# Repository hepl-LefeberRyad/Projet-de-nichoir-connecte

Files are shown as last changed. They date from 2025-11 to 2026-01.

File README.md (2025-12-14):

# Projet-de-nichoir-connecte
## Introduction
Dans ce répertoire, nous décrivons le projet final du premier quadrimestre pour le cours Smart Cities IoT. Le projet consiste en un nichoir intelligent capable de prendre des photos grâce à un ESP32 équipé d’une caméra intégrée. La caméra est déclenchée par un capteur de mouvement et est accompagnée d’une LED permettant d’éclairer l’intérieur du nichoir.

Les photos sont ensuite envoyées à un broker via le protocole MQTT et enregistrées dans une base de données. Elles sont également accessibles sur un site web.

Le projet intègre également une batterie, et une gestion énergétique a été mise en place afin que le nichoir puisse fonctionner pendant au moins six mois. Le niveau de batterie et la tension sont envoyés au broker une fois par jour.



## Matériel utilisés
### Timer cam
Le microcontrôleur principal de ce projet est une Timer Cam, qui contient un ESP32, une caméra ainsi qu’un port pour une batterie. Ce microcontrôleur est idéal pour ce type de projet de nichoir, puisque toutes les fonctionnalités nécessaires sont déjà intégrées sur une seule carte.
https://www.mouser.be/ProductDetail/170-U082

<p align="center">
  
</p>

### Raspberry pi
Le Raspberry Pi, qui agit comme broker et qui contient également la base de données dans laquelle les images seront enregistrées, est un Raspberry Pi 5. Il sert également à créer une page web sur laquelle on pourra consulter les images enregistrées, ainsi que l’heure et la date de prise de chaque photo, et le niveau de tension et de charge de la batterie. 
<p align="center">
  
</p>

### Capteur PIR
Le capteur de mouvement utilisé dans ce projet est un capteur PIR à 6 broches. Il s’agit d’un capteur intelligent qui intègre un circuit numérique et un élément sensible dans un boîtier hermétiquement fermé. Il peut s’interfacer directement avec jusqu’à deux capteurs PIR conventionnels via une entrée différentielle à haute impédance. Le signal PIR est converti en valeur numérique directement sur la puce. Une sortie REL indique lorsque le signal PIR dépasse le seuil sélectionné. L’entrée OEN peut contrôler la sortie REL ou passer par le capteur de lumière. Les paramètres de sensibilité et de durée de détection sont réglés en connectant les entrées correspondantes à des tensions continues (DC). Tout le traitement du signal est effectué numériquement. 
https://www.mouser.be/ProductDetail/485-5578
<p align="center">
  
</p>

### LED
Puisqu’il n’y a pas de lumière à l’intérieur du nichoir, nous utilisons une LED qui s’active uniquement lorsque la caméra prend une photo.
https://www.mouser.be/ProductDetail/442-BIRHO033ATB

### Régulateur de tension 3,3V
Puisque la tension de la batterie est supérieure à 3,3 V, il est nécessaire d’ajouter un régulateur de tension, car la tension idéale pour le fonctionnement du capteur de mouvement est de 3,3 V.
https://www.mouser.be/ProductDetail/584-ADP150AUJZ-3.3R7

### Mosfet
Puisque le courant consommé par la LED est supérieur à ce que la sortie GPIO de l’ESP32 peut fournir, nous avons dû implémenter un MOSFET. Ce MOSFET agit comme un interrupteur, permettant à la LED de s’allumer uniquement lorsqu’une impulsion est appliquée à sa gate. Un GPIO de l’ESP32 est connecté à cette gate.
https://www.mouser.be/ProductDetail/771-BSS138PS115

### Résistance et condensateurs
Nous avons également dû utiliser deux condensateurs, qui agissent comme des condensateurs de découplage entre l’entrée et la sortie du régulateur de tension. Deux résistances sont utilisées pour définir la sensibilité du capteur PIR, une résistance est placée en série avec la LED pour la protéger, et une autre résistance est utilisée sur la gate du MOSFET.

### Batterie 3,7 2000mAh
La batterie utilisée dans ce projet est une batterie de 3,7 V avec une capacité de 2000 mAh.
https://hobbyking.com/fr_fr/turnigy-2000mah-1s-1c-lipoly-w-2-pin-jst-ph-connector.html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

<p align="center">
  
</p>

## Logiciel utilisé
Pour programmer l’ESP32, nous avons utilisé Arduino IDE (version 2.3.5), qui simplifie le développement grâce à l’implémentation de nombreuses bibliothèques. Pour le Raspberry Pi, nous avons utilisé le langage Python (version 3.12) pour la gestion du MQTT. Nous avons également utilisé MariaDB et MySQL pour la création des bases de données et le traitement des données. Enfin, pour la création du site web, nous avons utilisé le langage HTML.

## Hardware
Pour assurer le bon fonctionnement du projet, il est indispensable de concevoir un PCB et un boîtier afin de protéger à la fois le PCB, les composants électroniques et la batterie. Nous avons créé le boîtier en le modélisant en 3D sur Fusion 360, puis nous l’avons imprimé. Pour la conception du PCB, nous avons utilisé Altium Designer version 25.8.1. 

<p align="center">
  <br><br>
  
</p>

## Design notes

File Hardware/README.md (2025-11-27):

# Hardware
## Introduction
Dans cette partie du répertoire, nous décrivons notre progrès concernant la partie matérielle du projet, comme le PCB ou le boîtier 3D.

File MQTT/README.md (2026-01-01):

# MQTT
## Introduction 
Dans cette partie du répertoire, nous documentons notre progrès dans l’implémentation du protocole MQTT pour notre projet. Un dossier contient notre progrés avec le code en Arduino l'autre avec notre progrés en RP.
# ESP32 Communication par MQTT

## Introduction
Ce dossier contient les codes liés à la communication MQTT du module ESP32 5TimerCam. Les codes permettent d'envoyer au broker MQTT des topics contenant des données textuelles ainsi que des images.  
Les codes sont dévelloppés sur l'environnement Arduino IDE et incluent la gestion de la connexion internet du côté subscriber. 
L'échange de données s'effectue sur le réseau local, via l'adresse IP du broker MQTT.

---
## Patch hepl-SousaJoao-patch-4#  

**Objectif** 
Ce code met en place un système de double réveil pour la TimerCAM :
- Réveil immédiat via le capteur PIR pour signaler un mouvement
- Réveil périodique via le timer RTC toutes les 60 secondes
Le tout en maintenant une consommation minimale grâce au deep sleep et à un timer permanent synchronisé.

1. Configuration matérielle
- LED externe sur le GPIO4
- Capteur PIR sur le GPIO13
- TimerCAM initialisée au démarrage
- RTC interne utilisé pour mesurer le temps et programmer les réveils

2. Gestion des causes de réveil
Au démarrage, le code identifie la source du réveil :

a) Réveil par PIR (EXT0)
- Le PIR est passé à HIGH
- La LED externe s’allume pendant 10 secondes
- Puis elle s’éteint avant le retour en deep sleep
  Ce comportement simule une action simple lors d’un mouvement détecté.

b) Réveil par Timer RTC
- Le timer interne a atteint l’échéance programmée
- Le code affiche simplement : "Reveil par timer permanent"
  Ce réveil sert uniquement à maintenir la synchronisation du timer.

c) Premier démarrage / reset
- Initialisation du timer permanent
- next_wakeup = now + PERIOD_US
  Le premier réveil périodique est programmé exactement 60 secondes plus tard.

3. Timer RTC permanent 
Le code utilise une variable RTC persistante :
RTC_DATA_ATTR uint64_t next_wakeup;

Elle survit au deep sleep et permet de :
- Garder une échéance fixe dans le temps
- Éviter toute dérive, même après plusieurs réveils PIR
- Recalculer la durée restante avant le prochain réveil
Logique :
- On lit l’heure RTC 
- On calcule le temps restant
- Ce temps restant est utilisé pour programmer le prochain réveil timer

Le réveil périodique reste parfaitement aligné toutes les 60 secondes.

4. Réactivation des sources de réveil
Avant chaque deep sleep :
- Le capteur PIR est activé :
esp_sleep_enable_ext0_wakeup(SENSOR_PIN, 1);
- Timer RTC est activé avec la durée restante :
esp_sleep_enable_timer_wakeup;
Ainsi, l’ESP32 peut être réveillé :
- Instantanément par un mouvement
- Régulièrement par le timer interne
- Sans conflit entre les deux mécanismes

5. Deep sleep
Enfin, le module entre en veille profonde:

esp_deep_sleep_start();

Le loop() n’est jamais exécuté : tout se passe dans setup() à chaque réveil.

---

## Patch hepl-SousaJoao-patch-5# 
**Objectif** 

Ce firmware combine deux mécanismes de réveil pour la TimerCAM :
     - Réveil PIR pour allumer une LED lors d’un mouvement
     - Réveil périodique RTC toutes les 60 secondes
Le tout avec une fenêtre PIR de 10 minutes limitant le nombre d’activations à 2, et un timer permanent synchronisé pour éviter toute dérive temporelle.

1. Configuration matérielle
     - LED externe sur le pin GPIO4
     - Capteur PIR sur le pin GPIO13 
     - TimerCAM initialisée au démarrage
     - RTC interne utilisé pour mesurer le temps et gérer les fenêtres

2. Gestion du réveil PIR
Lors d’un réveil par le capteur PIR :
     - Vérification de la fenêtre PIR de 10 minutes :
     - Si première activation ou fenêtre expirée: remise à zéro, déboute une nouvelle fenêtre
     - Limitation à 2 déclenchements de la LED.
     - La LED s'allumée pendant 10 secondes
     - Sinon la LED est ignorée quand la limite est atteinte

Ce mécanisme évite les déclenchements répétés et stabilise la consommation.

3. Réveil par Timer RTC
Si le réveil provient du timer interne :
     - Le code affiche simplement :"Reveil par timer permanent"
Ce réveil n’exécute aucune action fonctionnelle :
il sert uniquement à maintenir la synchronisation du timer permanent.

4. Premier démarrage
 Lors d’un reset ou du tout premier boot :
   - Initialisation du timer permanent :
     - Initialisation de la fenêtre PIR
     - Remise à zéro du compteur PIR

5. Timer RTC permanent 
 Le code utilise une variable RTC persistante :

 Elle permet de :
  - Garder une échéance fixe toutes les 60 secondes
  - Recalculer le temps restant avant le prochain réveil
  - Éviter toute dérive, même après plusieurs réveils PIR
 
 Logique :
  -  Si l’heure actuelle dépasse l’échéance alors on programme la suivante
  -  Sinon, on calcule le temps restant
  -  Ce temps est utilisé pour programmer le réveil RTC

6. Activation des sources de réveil
 Avant chaque deep sleep :
  - Le capteur PIR activé
  - Timer RTC est activé avec la durée restante

Ainsi, l’ESP32 peut être réveillé :

  - Instantanément par le PIR
  - Régulièrement par le timer RTC
  - Sans conflit entre les deux mécanismes

---

## Patch hepl-SousaJoao-patch-6#  
**Objectif** 
Gestion PIR limitée, envoi batterie MQTT et timer RTC synchronisé.
Ce code met en ouvre un fonctionnement basse consommation combinant trois mécanismes indépendants:
- Déclenchement par le capteur PIR limité à deux activations dans une fenêtre de dix minutes.
- Envoi périodique de l’état de la batterie via MQTT lors d’un réveil par timer RTC.
- Deep sleep systématique avec double source de réveil : capteur PIR (EXT0) et timer RTC.
L’ensemble garantit une consommation minimale tout en assurant un comportement prévisible et synchronisé.

1. Configuration matérielle et réseau
- LED sur GPIO4
- PIR sur GPIO13 (réveil EXT0)
- TimerCAM initialisée au démarrage
- Wi‑Fi activé uniquement lors des transmissions MQTT
- MQTT configuré avec un broker local et un topic batterie

2. Gestion du réveil PIR
Lors d’un réveil PIR :
- Vérification de la fenêtre de dix minutes ; réinitialisation si expirée
- Si pir_count < 2, l’activation est acceptée : incrément du compteur et LED allumée dix secondes
- Si la limite est atteinte, aucune action n’est effectuée
Ce mécanisme limite les déclenchements et réduit la consommation.

3. Réveil par timer RTC et envoi de la batterie
Lors d’un réveil TIMER :
- Lecture du niveau et de la tension de batterie
- Construction d’un message unique
- Activation du Wi‑Fi, connexion MQTT, publication sur timercam/battery
- Désactivation immédiate du Wi‑Fi
Le Wi‑Fi n’est utilisé que pour l’envoi, ce qui optimise l’énergie.

4. Premier démarrage
En cas de reset :
- Initialisation du timer permanent, prochaine échéance dans une minute
- Initialisation de la fenêtre PIR
- Remise à zéro du compteur PIR

5. Timer RTC permanent et synchronisation
Le timer utilise next_wakeup stocké en RTC pour maintenir une périodicité stable :
- Si l’échéance est dépassée, une nouvelle est programmée
- Sinon, le temps restant est calculé
- Le timer RTC est configuré avec cette durée
Ce procédé évite toute dérive, même après plusieurs réveils PIR.

6. Activation des sources de réveil
Avant chaque deep sleep :
- Activation du réveil PIR (EXT0)
- Activation du réveil TIMER avec la durée restante
L’ESP32 peut ainsi être réveillé soit par un mouvement, soit par le timer périodique.

---    

## Patch hepl-SousaJoao-patch-7#
**Objectif :** Envoi d'une photo MQTT après détection de mouvement prolongée.  
Le but est de détecter un mouvement via un capteur PIR, attendre que ce mouvement dure au moins 10 secondes, capturer une photo avec la TimerCAM et l’envoyer vers un broker MQTT en morceaux (chunks) encodés en Base64.

- Configuration matérielle
  - Capteur PIR connecté sur la pin 13
  - Lecture en numérique : HIGH = mouvement détecté
  - TimerCAM initialisée en mode caméra JPEG
  - Résolution configurée en XGA 
  - Orientation verticale inversée via set_vflip(1)

- Connexion WiFi
  - Connexion au réseau WiFi défini dans les macros WIFI_SSID et WIFI_PASSWORD
  - Timeout de connexion fixé à 10 secondes 
  - Reconnexion automatique activée
  - Affichage de l’adresse IP en cas de réussite

- Communication MQTT
  - Utilisation de la librairie PubSubClient
  - Connexion au broker MQTT défini par :
    - MQTT_HOST
    - MQTT_PORT
    - MQTT_TOPIC
  - Reconnexion automatique si la communication MQTT est perdue
  - Envoi des messages via mqttClient.publish

- Détection de mouvement
  - La logique du PIR fonctionne en trois phases :
    
    1 - Détection du front montant
       - Passage LOW à HIGH
         
       - Début de la temporisation : motionStart = millis()
         
       - Le flag photoTaken = false réactive la prise de photo

    2 - Maintien du mouvement
       - On attend 10 secondes de mouvement continu
         
       - Condition : millis() - motionStart >= 10000
         
       - Une fois la durée atteinte une photo est capturée

    3 - Fin du mouvement
       - Passage HIGH à LOW
         
       - Reset de l’état du capteur

- Capture et envoi de la photo
  - Prise de vue via TimerCAM en JPEG
  - Découpage de l’image en blocs de 4 KB
  - Encodage en Base64 pour compatibilité MQTT
  - Transmission séquentielle de tous les chunks
  - Libération de la mémoire caméra
    
---

## Patch hepl-SousaJoao-patch-8#
**Objectif :** Envoi d'une photo MQTT après détection de mouvement prolongée avec une mise en veille.  
Détecter un mouvement continu durant 10 secondes, activer le WiFi, envoyer une photo via MQTT, puis repasser l’ESP32 TimerCAM en mode veille profonde avec réveil par le capteur PIR.

- Configuration matérielle
  - Capteur PIR sur GPIO13
  - TimerCAM initialisée en mode JPEG
  - Résolution XGA
  - Orientation verticale ajustée et qualité optimisée
  - Port série actif pour le debug

- Détection de mouvement 
  - Le PIR pilote l’ensemble du fonctionnement à travers trois phases :
    - Début du mouvement
      - Passage de LOW à HIGH.
      - Enregistrement du temps de début.
      - La prise de photo n’est pas encore autorisée.

    - Mouvement continu pendant 10 secondes
      - Si le PIR reste HIGH pendant 10 secondes il y a un déclenchement de la capture.
      - Le système sait que le mouvement est réel et persistant.

    - Fin du mouvement
      - Retour à LOW ainsi le retour à l’état initial.

- Connexion WiFi

  - Activation du WiFi uniquement lorsque la photo doit être envoyée.
  - Connexion au point d’accès défini dans le code.
  - Affichage de l’adresse IP pour vérifier la liaison.
  - Extinction complète du WiFi après envoi pour économiser l’énergie.

- Communication MQTT

  - Configuration du broker: L'adresse IP, port et topic.
  - Connexion MQTT juste avant l’envoi de la photo.
  - Reconnexion si nécessaire.
  - Transmission d’un message texte “Photo taken” après l’image.

- Capture et envoi de la photo

  - Capture JPEG via TimerCAM.
  - Découpage en blocs de 4 KB.
  - Encodage Base64 pour compatibilité MQTT.
  - Envoi séquentiel de chaque chunk identifié par:
    - ID unique: timestamp.
    - Numéro du chunk.
    - Nombre total de chunks.
  - Libération du buffer caméra après transmission.

- Mise en veille après envoi
  
  - Extinction complète du WiFi: disconnect et WIFI_OFF.
  - Attente du retour du PIR à LOW jusqu’à 10 secondes.
  - Configuration du réveil via ext0_wakeup sur le PIR.
  - Passage en deep sleep pendant 20 secondes via TimerCAM si aucune photo est prise.
    - Cela permet :
      - Réduction très forte de la consommation énergétique.
      - Réveil automatique dès qu’un nouveau mouvement est détecté.
---

## Patch hepl-SousaJoaopatch-9#
**Objectif :** Envoi d'une photo MQTT avec flash après détection de mouvement prolongée avec une mise en veille .  
Détecter un mouvement continu durant 10 secondes, signaler la prise de photo via une LED externe, envoyer l’image en plusieurs blocs sur MQTT, puis repasser l’ESP32 TimerCAM en mode veille profonde avec réveil via le PIR.

- Configuration matérielle
  - Capteur PIR connecté sur GPIO13
  - LED externe sur GPIO4
  - TimerCAM initialisée pour capturer en JPEG 
  - Port série configuré pour le suivi en temps réel
  - Paramètres MQTT définis: broker local, topic

- Détection du mouvement
  - Le programme suit l’évolution du signal du PIR :
  - Début du mouvement: LOW à HIGH
  - Enregistrement du temps de début
  - Indication dans le terminal
  - L’appareil se prépare mais ne prend pas encore de photo

- Mouvement continu pendant 10 secondes
  - Vérification via millis()
  - Ce seuil valide que la présence détectée est réelle et prolongée

- Fin du mouvement 
  - Réinitialisation du système
  - Retour en état d’attente

- Indication lumineuse
  - La LED s’allume juste avant la capture photo
  - Elle reste active pendant la transmission MQTT
  - Elle s’éteint 2 secondes après la photo, comme flash

- Connexion WiFi et communication MQTT
  - Activation du WiFi uniquement lors de la prise de photo
  - Connexion au réseau local configuré
  - Connexion MQTT au broker via un client PubSub
  - Envoi d’un message “Photo taken” après le transfert de l’image
  - Désactivation totale du WiFi après transmission

- Capture et envoi de la photo
  - Capture JPEG via TimerCAM
  - Découpage du fichier en blocs de 4 KB
  - Encodage Base64 de chaque bloc
  - Envoi sur le topic MQTT sous forme de paquets :

    - ID de l’image
      - Numéro du bloc
      - Nombre total de blocs
      - Données base64

  - Libération du buffer caméra après transmission

- Mise en veille et gestion du réveil
  - Attente que le PIR repasse à LOW avant d’autoriser la veille
  - Configuration du réveil matériel via ext0_wakeup sur le capteur PIR
  - Passage en mode deep sleep pendant 20 secondes si aucune photo est prise
  - L’ESP32 se réveillera automatiquement lorsqu’un nouveau mouvement est détecté

    - Ce fonctionnement permet :
      - Une détection fiable
      - Une transmission réseau efficace
      - Une consommation d’énergie minimale grâce à la veille profonde

---

## Patch hepl-SousaJoaopatch-10# 
**Objectif :** Détecter un mouvement continu pendant 10 secondes, capturer une photo, l’envoyer en blocs via MQTT, puis remettre la TimerCAM en deep sleep avec double réveil :
   - Par capteur PIR (EXT0) pour prendre les photos
   - Par timer RTC pour l’envoi périodique du niveau de batterie.
 Ce patch combine détection fiable, transmission optimisée, et gestion d’énergie avancée.

1. Configuration matérielle
   - Capteur PIR sur le GPIO13
   - LED externe sur GPIO4
   - TimerCAM initialisée pour capturer en JPEG 
   - WiFi activé uniquement lors des transmissions
   - MQTT : broker local, topics pics et timercam/battery

2. Détection du mouvement avec la PIR:

   - Vérification que le PIR est HIGH 
   - Démarrage d’une fenêtre de 10 secondes via millis()
   - Si le signal reste stable : photo autorisée
   - Sinon : retour immédiat en veille
  Une limite de 2 photos par fenêtre de 10 minutes est imposée via :
   - window_start (timestamp RTC)
   - pir_count => compteur de photos max. 2 photos par fenêtre de temps

3. Capture et envoi de la photo

 Si le mouvement est continu pendant 10 secondes:
   - Initialisation caméra
   - Capture JPEG
   - Découpage en blocs de 4095 bytes
   - Encodage Base64
   - Envoi MQTT sous forme de données_base64
   - Message final : "Photo taken"
   - Libération du buffer caméra
   - Désactivation du WiFi

4. Envoi périodique de la batterie (réveil par le TIMER)
 Toutes les 1 minute, un réveil RTC est déclenché :
   - Lecture tension + pourcentage batterie
   - Connexion WiFi + MQTT
   - Publication sur timercam/battery
   - Retour en deep sleep
 Ce réveil n’interfère pas avec la logique PIR.

5. Gestion des timers RTC 
 a) Réveil toutes les 60 secondes pour envoyer l’état batterie.
    #define PERIOD_US (60ULL * 1000000ULL)

 b) WINDOW_US – Fenêtre PIR de 10 minutes
    Limite de 2 photos par fenêtre de 10 minutes.
    Si la fenêtre expire, pir_count est remis à zéro. 
    #define WINDOW_US (10ULL * 60ULL * 1000000ULL)

 c) next_wakeup – Synchronisation continue
    Stocké en RTC_DATA_ATTR, donc conservé en deep sleep.
    Logique :
   - On calcule le temps restant avant le prochain réveil périodique
   - On programme le timer RTC avec ce temps
   - On met à jour next_wakeup = now + remaining

 Le réveil batterie reste parfaitement synchronisé, même si plusieurs réveils PIR interviennent entre-temps.

  6. Mise en veille et réveils
   
  Avant de dormir :
   - Activation du réveil PIR :
     esp_sleep_enable_ext0_wakeup(SENSOR_PIN, 1)
   - Activation du réveil timer :
     esp_sleep_enable_timer_wakeup(remaining)
   - Passage en deep sleep
 Ce fonctionnement assure :
   - Réactivité avec un réveil instantané sur mouvement
   - Régularité avec le niveau de batterie envoyée toutes les 60 s
   - Économie d’énergie maximale

---

## Patch hepl-SousaJoaopatch-11#
**Objectif** L’objectif est de faire fonctionner la TimerCAM en ultra basse consommation en combinant trois fonctions totalement indépendantes : la prise de photo uniquement lorsqu’un mouvement est validé par le capteur PIR, l’envoi périodique de l’état de la batterie via MQTT, et un mode deep sleep optimisé utilisant deux sources de réveil — le PIR pour les photos et le timer RTC pour les transmissions programmées.

1. Matériel et configuration
   
- Capteur PIR sur le pin GPIO13 (EXT0)
- LED externe sur le pin GPIO4
- Initialisation de la TimerCAM
- Initialisation du Wi-Fi
- Initialisation de la communication par MQTT 

2. Réveil par détection d'un mouvement par le capteur PIR  
 Au réveil par le PIR :

 - Vérification du contexte s'il n'y a pas de blocage ou si la fenêtre PIR active
 - Validation du mouvement :
  - Observation du PIR pendant 10 s
  - Le signal doit rester majoritairement HIGH
  - Sinon: retour en deep sleep
 - Limitation : 2 photos maximum par fenêtre de 12h  
  - window_start = début de fenêtre
  - pir_count = nombre de photos prises

3. Capture & envoi photo
   
Si le mouvement est validé :
- Initialisation caméra
  - Capture d'une image
  - Découpage en blocs de 4095 octets
  - Encodage Base64
  - Envoi MQTT des chunks de la photo
  - Message final : "Photo taken"
  - Libération mémoire + coupure Wi-Fi
- Activation d’un blocage PIR de 5 minutes

4. Blocage PIR
   
Après chaque photo :
- Le PIR est ignoré pendant 5 minutes
- Le timer RTC gère automatiquement la fin du blocage
- Objectif : éviter les rafales et réduire la consommation

5. Batterie réveil par TIMER
   
Un réveil RTC indépendant envoie la batterie toutes les 24 h :
- Lecture tension + le pourcentage de la batterie
- Publication MQTT sur battery
- Coupure Wi-Fi
- Retour en deep sleep
Ce réveil fonctionne même si plusieurs réveils PIR ont eu lieu entre-temps.

6. Gestion des timers RTC
   
- Timer batterie :
- Stocké en RTC
- Toujours aligné sur un multiple exact de 24 h
- Fenêtre PIR :
- Durée : 12 h
- À expiration alors pir_count = 0
- Avant chaque deep sleep :
- Calcul du prochain événement :
- Envoi batterie
- Fin blocage capteur PIR
- Fin fenêtre capteur PIR
- Le plus proche détermine la durée du sommeil

7. Mise en veille
   
Avant de dormir :
- Timer RTC toujours actif
- PIR activé uniquement si : Pas de blocage ou si la fenêtre PIR n'est pas saturée.
- Fenêtre PIR non saturée

Réveil après dormir si :
- Réveil instantané sur mouvement valide
- Batterie envoye les données régulièrement
- Ce qui permet une consommation minimale

---

## Patch hepl-SousaJoaopatch-12#

**Objectif** Faire fonctionner la TimerCAM en ultra basse consommation : capture photo uniquement sur mouvement validé par le PIR, envoi périodique de la batterie via MQTT, et deep sleep optimisé avec GPIO33 pour alimentation de la caméra, capteur PIR et les timers RTC.

1. Matériel et configuration

- Capteur PIR sur le pin GPIO13 (EXT0)
- LED externe sur le pin GPIO4
- Initialisation du  GPIO33 poour commuter la batterie
- Initialisation de la TimerCAM
- Initialisation du Wi-Fi
- Initialisation de la communication par MQTT 
- GPIO 33 est mis sur HIGH en permanence

2. Réveil par détection d'un mouvement par le capteur PIR  
 Au réveil par le PIR :

 - Vérification du contexte s'il n'y a pas de blocage ou si la fenêtre PIR active
 - Validation du mouvement :
  - Observation du PIR pendant 10 s
  - Le signal doit rester majoritairement HIGH
  - Sinon: retour en deep sleep
 - Limitation : 2 photos maximum par fenêtre de 12h  
  - window_start = début de fenêtre
  - pir_count = nombre de photos prises

3. Capture & envoi photo
   
Si le mouvement est validé :
- Initialisation caméra
  - Capture d'une image + envois de la topic de la batterie
  - Découpage en blocs de 4095 octets
  - Encodage Base64
  - Envoi MQTT des chunks de la photo
  - Message final : "Photo taken"
  - Libération mémoire avec coupure Wi-Fi
- Activation d’un blocage PIR de 5 minutes

4. Blocage PIR
   
Après chaque photo :
- Le PIR est ignoré pendant 5 minutes
- Le timer RTC gère automatiquement la fin du blocage
- Objectif : éviter les rafales et réduire la consommation

5. Batterie réveil par TIMER
   
Un réveil RTC indépendant envoie la batterie toutes les 24 h :
- Lecture tension + le pourcentage de la batterie
- Publication MQTT sur battery
- Coupure Wi-Fi
- Retour en deep sleep
Ce réveil fonctionne même si plusieurs réveils PIR ont eu lieu entre-temps.

6. Gestion des timers RTC
   
- Timer batterie :
- Stocké en RTC
- Toujours aligné sur un multiple exact de 24 h
- Fenêtre PIR :
- Durée : 12 h
- À expiration alors pir_count = 0
- Avant chaque deep sleep :
- Calcul du prochain événement :
- Envoi batterie
- Fin blocage capteur PIR
- Fin fenêtre capteur PIR
- Le plus proche détermine la durée du sommeil

7. Mise en veille
   
Avant de dormir :
- Timer RTC toujours actif
- PIR activé uniquement si : Pas de blocage ou si la fenêtre PIR n'est pas saturée.
- Fenêtre PIR non saturée

Réveil après dormir si :
- Réveil instantané sur mouvement valide
- Batterie envoye les données régulièrement
- Ce qui permet une consommation minimale

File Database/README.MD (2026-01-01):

# Database

## Introduction
Ce dossier contient le code et les scripts relatifs à la gestion des données du projet SmartCitiesIoT – Nichoir.  
Il inclut la configuration de la base de données MariaDB, la création de tables pour stocker les messages et les images envoyés par l'ESP32 via MQTT, ainsi que les scripts Python pour insérer et récupérer ces données.

---

## Patch #1
**Objectif :** Gestion des messages envoyés par l'ESP32 via MQTT.  
- Création de la base `IMAGE` et de la table `messages`.  
- Champs principaux de la table `messages` :
  - `id` : identifiant unique auto-incrémenté.  
  - `topic` : topic MQTT associé au message.  
  - `payload` : contenu du message (texte).  
  - `timestamp` : date et heure de réception automatique.  
- Script Python fourni pour :
  - Créer la table si elle n’existe pas (`create_table()`).  
  - Recevoir des messages MQTT et les insérer dans la base (`insert_message()`).  
- Utilisation d’un client MQTT en Python (`paho-mqtt`) avec gestion de la reconnexion automatique.

---

## Patch #2
**Objectif :** Réception et stockage des images envoyées en un seul paquet.  
- Création de la table `images` pour stocker les photos.  
- Champs principaux :
  - `id` : identifiant unique auto-incrémenté.  
  - `topic` : topic MQTT associé à l'image.  
  - `payload` : données binaires de l'image (BLOB).  
  - `timestamp` : date et heure de réception.  
- Script Python fourni pour :
  - Décoder les images envoyées en Base64.  
  - Sauvegarder les images :
    - Dans le dossier local `/home/joao1/received_images`.  
    - Dans la base de données MariaDB (`images`).  
- Gestion des erreurs de connexion et de décodage des images.

---

## Patch #3
**Objectif :** Gestion des images envoyées en plusieurs morceaux (chunking).  
- Réception des images chunkées pour permettre l’envoi de fichiers plus volumineux.  
- Structure temporaire : dictionnaire `image_chunks` pour stocker les morceaux d’images en mémoire.  
- Fonctionnalités principales :
  - Assemblage des chunks dans le bon ordre pour reconstituer l'image complète.  
  - Décodage Base64 de l’image reconstituée.  
  - Sauvegarde automatique :
    - Dans le dossier local `/home/joao1/received_images`.  
    - Dans la base de données MariaDB (`images`) avec `imageID`.  
  - Gestion de la mémoire pour supprimer les chunks après assemblage.  
  - Logs détaillés pour suivre la réception et le traitement des images.

--- 
## Patch #10
**Objectif :** Gestion des images envoyées en plusieurs morceaux (chunking) et ajout de la réception des informations de batterie via MQTT.

### Nouveautés
- **Gestion du topic batterie (`battery`)**
  - Prise en charge des messages MQTT envoyés par l'ESP32 contenant l’état de la batterie.
  - Format attendu : `"LEVEL,VOLTAGE"` (exemple : `"85,3700"`).
  - Extraction automatique de :
    - `battery_level` : niveau de batterie en pourcentage.
    - `battery_voltage` : tension en millivolts.
  - Affichage des informations dans les logs avec horodatage.
  - Gestion des erreurs pour les messages mal formés ou inattendus.

- **Adaptation des callbacks MQTT**
  - Les callbacks gèrent désormais simultanément :
    - Le topic images (`pics`) avec réception chunkée.
    - Le topic batterie (`battery`) sans perturber le traitement des images.

- **Suivi temps réel de l’état énergétique**
  - Permet de suivre l’état de la batterie de l’ESP32 via MQTT en parallèle de la réception et de la sauvegarde des images.

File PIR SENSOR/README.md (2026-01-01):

# PIR SENSOR

## Introduction
Ce dossier contient les codes de base relatifs à la gestion du capteur PIR 5578 BS-612 sur un ESP32 5TimerCam.  
Ce code est écrit sur l'environnement Arduino IDE et permet la configuration de base du capteur, ainsi que contrôler les moyens d'activation et désactivation du capteur.

---

## Patch hepl-SousaJoao-patch-1#
**Objectif :** Test simple du capteur BS-612 qui contrôle l'état d'une led.  

- Configuration des pins du matérielle
  - Le capteur PIR BS-612 est configuré comme une entrée sur le GPIO13.
  - La led est configuré comme sortie sur le pin GPIO4.
- Lecture de l'état du capteur
  - Il y a une surveillance continue de l'état logique du capteur PIR.
  - Lorsqu'il y a une détection d'un front montant, le capteur se met en état HIGH.
- Activation de la LED
  - La led s'allume lors de la détection
  - Grâce au compteur millis(), le programme peut vérifier si la led est allumée depuis 5000ms.
- Gestion de la temporisation
  - Comptage jusqu'à 5000ms avant que la led s'éteint.
  - Utilisation d'un flag (ledActive) pour éviter des déclenchements répétés.
- Coupure automatique de la led
  - La led s'éteint.   

## Patch hepl-SousaJoao-patch-2#
**Objectif :** Détecter un mouvement avec le capteur PIR BS-612 et allumer la led uniquement si le mouvement dure au moins 5 secondes.  

- Configuration des pins du matérielle
  - Le capteur PIR BS-612 est configuré  sur le GPIO13 et la led sur le pin GPIO4.
  - L'initialisation de la led à l'état LOW.
- Lecture de l'état du capteur
  - Il y a une surveillance continue de l'état logique du capteur PIR.
  - Lorsqu'il y a une détection d'un front montant, le capteur se met en état HIGH.
- Démarrage du chronomètre sur détection
  - Quand un mouvement est capté, pour la première fois:
    - motionDetected = true
    - motionStartTime = millis(), il y a un enregistrement du moment du début du mouvement.
- Vérification de la durée du mouvement
  - Si le mouvement continue est égale ou dépasse 5 secondes alors:
    - La led s'allume.
    - Un message est envoyé sur le terminal:
- Réinitialisation si pas de mouvement
  - motionDeected = false
  - si la led est allumée, et il n'y a plus de mouvement continue: la led s'éteint.

## Patch hepl-SousaJoao-patch-3#
**Objectif :** Réveil du microcôntroleur grâce au capteur PIR BS-612.  

- Configuration des pins du matérielle
  - Le capteur PIR BS-612 est configuré  sur le GPIO13 et la led sur le pin GPIO4.
  - L'initialisation de la led à l'état LOW.
- Réveil par bouton ou capteur
  - Autorisation du réveil depuis l’état de sommeil profond (esp_sleep_enable_ext0_wakeup)
  - Niveau bas sur le bouton ou le capteur déclenche le réveil
  - Permet de garder l’appareil en veille pour économiser de l’énergie
- Gestion du TimerCAM
  - Initialisation du module TimerCAM (TimerCAM.begin(true))
  - Commande d’allumage de la LED via PWM 
  - LED allumée pendant 10 secondes pour indiquer le réveil

- Mise en veille automatique
  - Après affichage / temporisation, l’appareil peut se mettre en veille
  - Le réveil peut être déclenché par :
  - le capteur PIR
  - le bouton physique
  - La fonction TimerCAM.Power.timerSleep(5) déclenche la mise en veille après 5 secondes

- Utilisation du compteur / temporisation
  - vTaskDelay(pdMS_TO_TICKS(10000)) = pause non bloquante pendant 10 secondes avant de lancer la veille
  - Permet d’avoir un délai avant la mise en veille tout en restant compatible avec le multitâche

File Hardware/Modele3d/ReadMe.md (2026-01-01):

## Modele3d
Dans ce dossier on retrouve les modèles 3d de notre projet. Volume 1 était un premier boîtier qu'on a developpé et volume 2 est le prototype final.

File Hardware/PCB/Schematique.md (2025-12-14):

# Schematique 
La schématique suivante montre le branchement des composants principaux du projet.



## MOSFET et LED
La tension provient du pin Nr3 du bus de la Timer Cam. Le pin Nr1 du bus correspond au GPIO 13, utilisé pour le capteur PIR, tandis que le pin Nr2 correspond au GPIO 4. Le GPIO 4 est connecté à la gate du MOSFET, et à la source, on trouve une résistance en série avec la LED.

Lorsqu’une impulsion est envoyée sur le GPIO 4, le MOSFET conduit et la LED est connectée à la masse, ce qui permet son allumage.

Pour cette application, nous avons utilisé un IC avec deux MOSFET intégrés, car le MOSFET idéal n’était plus disponible chez Mouser. Le MOSFET choisi est le BSS138PS, adapté pour être activé directement par un GPIO d’un ESP32.
La résistance R4, en série avec la LED, limite le courant à 50 mA et fait chuter la tension de 3,3 V à 1,3 V, protégeant ainsi la LED. La résistance R1, en série avec la gate du MOSFET, limite le courant de charge instantané de la gate à environ 10 mA, protégeant le GPIO de l’ESP32 tout en assurant une commutation rapide. Ces deux résistances garantissent donc la sécurité et le fonctionnement fiable du circuit.

### Caractéristiques du BSS138PS:
- Courant maximal : 320 mA (suffisant pour notre LED consommant 50 mA max)
- Tension drain-source maximale : 60 V
- Tension gate-source maximale : ±20 V
- Tension seuil gate-source (VGS(th)) : 0,9 – 1,5 V

## Régulateur de tension
Nous avons également utilisé le régulateur ADP150AUJZ-3,3R7, un régulateur à ultra faible bruit garantissant une tension de sortie stable de 3,3 V. Deux condensateurs de découplage de 1 µF sont branchés respectivement à l’entrée et à la sortie du régulateur de tension.

### Caractéristiques principales :
- Tension d’entrée : 2,2 V à 5,5 V

- Courant maximal : 150 mA (largement suffisant pour notre application)

## Résistance au Pin REL du PIR
Le pont diviseur, composé de R3 et R2, permet de régler la sensibilité du capteur. Plus la tension au point de mesure se rapproche de 0 V, plus le capteur est sensible. Dans notre application, nous avons utilisé 100 Ω et 1 kΩ. T1 représente un point de test permettant de mesurer la tension du diviseur.
# PCB
Le PCB a été commandé chez EUROCIRCUIT et présente une taille compacte de 3,3 cm de largeur sur 4,3 cm de longueur, afin de s’insérer facilement dans un petit boîtier, minimisant ainsi l’encombrement dans le nichoir. Il comporte deux couches et intègre à la fois des composants SMD et through-hole.
<p align="center">
 
</p>

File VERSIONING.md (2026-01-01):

# Versioning

Chaque changement apporté aux codes a été réalisé en utilisant une nouvelle branche.  
La branche `main` contient le code principal avec l’ensemble des fonctionnalités du projet.

Dans chaque branche créée, un fichier README décrit les changements apportés aux différents fichiers du code.  
Dans ce README, nous rassemblons l’ensemble des différents patchs appliqués à notre projet afin d’assurer un suivi clair et structuré de son évolution.

## Patchs effectuer par Ryad
---

## Patch #1
**Objectif :** Gestion des messages envoyés par l'ESP32 via MQTT.  
- Création de la base `IMAGE` et de la table `messages`.  
- Champs principaux de la table `messages` :
  - `id` : identifiant unique auto-incrémenté.  
  - `topic` : topic MQTT associé au message.  
  - `payload` : contenu du message (texte).  
  - `timestamp` : date et heure de réception automatique.  
- Script Python fourni pour :
  - Créer la table si elle n’existe pas (`create_table()`).  
  - Recevoir des messages MQTT et les insérer dans la base (`insert_message()`).  
- Utilisation d’un client MQTT en Python (`paho-mqtt`) avec gestion de la reconnexion automatique.

---

## Patch #2
**Objectif :** Réception et stockage des images envoyées en un seul paquet.  
- Création de la table `images` pour stocker les photos.  
- Champs principaux :
  - `id` : identifiant unique auto-incrémenté.  
  - `topic` : topic MQTT associé à l'image.  
  - `payload` : données binaires de l'image (BLOB).  
  - `timestamp` : date et heure de réception.  
- Script Python fourni pour :
  - Décoder les images envoyées en Base64.  
  - Sauvegarder les images :
    - Dans le dossier local `/home/joao1/received_images`.  
    - Dans la base de données MariaDB (`images`).  
- Gestion des erreurs de connexion et de décodage des images.

---

## Patch #3
**Objectif :** Gestion des images envoyées en plusieurs morceaux (chunking).  
- Réception des images chunkées pour permettre l’envoi de fichiers plus volumineux.  
- Structure temporaire : dictionnaire `image_chunks` pour stocker les morceaux d’images en mémoire.  
- Fonctionnalités principales :
  - Assemblage des chunks dans le bon ordre pour reconstituer l'image complète.  
  - Décodage Base64 de l’image reconstituée.  
  - Sauvegarde automatique :
    - Dans le dossier local `/home/joao1/received_images`.  
    - Dans la base de données MariaDB (`images`) avec `imageID`.  
  - Gestion de la mémoire pour supprimer les chunks après assemblage.  
  - Logs détaillés pour suivre la réception et le traitement des images.

--- 
---

### Patch 4 – Ajout du serveur Flask pour récupérer les messages MQTT
- **Fichier modifié :** `app.py`
- **Ajouts :**
  - Création d'un serveur Flask minimal.
  - Connexion à MariaDB pour récupérer les messages MQTT.
  - Route `/` qui affiche les messages dans une page HTML via `render_template`.
  - Fonction `get_messages()` pour interroger la table `messages`.
  - Serveur prêt à afficher les messages côté web.

---

### Patch 5 – Ajout de la page HTML pour l’affichage des messages
- **Fichier ajouté :** `index.html`
- **Ajouts :**
  - Interface web pour afficher les messages MQTT.
  - Tableau avec colonnes : `ID`, `Topic`, `Payload`, `Timestamp`.
  - Style CSS simple pour lisibilité et centrage du contenu.
  - Affichage dynamique des messages récupérés par Flask.

---

### Patch 6 – Ajout de la gestion des images dans Flask
- **Fichier modifié :** `app.py`
- **Ajouts :**
  - Gestion des images reçues via MQTT (Base64 pour le front).
  - Fonction `get_images()` pour récupérer les images depuis MariaDB.
  - Passage de la liste des images à la page HTML pour affichage.
  - Préparation du code pour afficher les images dans une interface web dédiée.

---

### Patch 7 – Page HTML pour afficher les images
- **Fichier ajouté :** `index.html`
- **Ajouts :**
  - Interface web pour visualiser les images envoyées via MQTT.
  - Chaque image affichée dans une carte avec ses informations : `id`, `topic`, `timestamp`.
  - Modal viewer pour agrandir les images au clic.
  - Auto-refresh toutes les 5 secondes pour mettre à jour les images côté front.

---

### Patch 8 – Ajout de la gestion de la batterie dans Flask
- **Fichier modifié :** `app.py`
- **Ajouts :**
  - Ajout d’un client MQTT pour recevoir les données de batterie (`level, voltage`).
  - Stockage temporaire des informations de batterie côté serveur (`battery_info`).
  - Les images sont toujours récupérées et envoyées au front.
  - Route `/` renvoie maintenant les images **et** les informations de batterie pour l’affichage.

---

### Patch 9 – Page HTML pour afficher images et batterie
- **Fichier modifié :** `index.html`
- **Ajouts :**
  - Bloc d’information sur la batterie en haut de la page (`Voltage`, `Capacity`, `Updated`).
  - Auto-refresh toutes les 5 secondes pour mettre à jour les images **et** les informations de batterie.
  - Modal viewer pour images maintenu pour l’interaction utilisateur.
  - Page complète affichant à la fois les images et l’état de la batterie.
--- 
## Patch #10
**Objectif :** Gestion des images envoyées en plusieurs morceaux (chunking) et ajout de la réception des informations de batterie via MQTT.

### Nouveautés
- **Gestion du topic batterie (`battery`)**
  - Prise en charge des messages MQTT envoyés par l'ESP32 contenant l’état de la batterie.
  - Format attendu : `"LEVEL,VOLTAGE"` (exemple : `"85,3700"`).
  - Extraction automatique de :
    - `battery_level` : niveau de batterie en pourcentage.
    - `battery_voltage` : tension en millivolts.
  - Affichage des informations dans les logs avec horodatage.
  - Gestion des erreurs pour les messages mal formés ou inattendus.

- **Adaptation des callbacks MQTT**
  - Les callbacks gèrent désormais simultanément :
    - Le topic images (`pics`) avec réception chunkée.
    - Le topic batterie (`battery`) sans perturber le traitement des images.

- **Suivi temps réel de l’état énergétique**
  - Permet de suivre l’état de la batterie de l’ESP32 via MQTT en parallèle de la réception et de la sauvegarde des images.
--- 

## Patchs effectuer par Joao
---
## Patch hepl-SousaJoao-patch-1#
**Objectif :** Test simple du capteur BS-612 qui contrôle l'état d'une led.  

- Configuration des pins du matérielle
  - Le capteur PIR BS-612 est configuré comme une entrée sur le GPIO13.
  - La led est configuré comme sortie sur le pin GPIO4.
- Lecture de l'état du capteur
  - Il y a une surveillance continue de l'état logique du capteur PIR.
  - Lorsqu'il y a une détection d'un front montant, le capteur se met en état HIGH.
- Activation de la LED
  - La led s'allume lors de la détection
  - Grâce au compteur millis(), le programme peut vérifier si la led est allumée depuis 5000ms.
- Gestion de la temporisation
  - Comptage jusqu'à 5000ms avant que la led s'éteint.
  - Utilisation d'un flag (ledActive) pour éviter des déclenchements répétés.
- Coupure automatique de la led
  - La led s'éteint.   

## Patch hepl-SousaJoao-patch-2#
**Objectif :** Détecter un mouvement avec le capteur PIR BS-612 et allumer la led uniquement si le mouvement dure au moins 5 secondes.  

- Configuration des pins du matérielle
  - Le capteur PIR BS-612 est configuré  sur le GPIO13 et la led sur le pin GPIO4.
  - L'initialisation de la led à l'état LOW.
- Lecture de l'état du capteur
  - Il y a une surveillance continue de l'état logique du capteur PIR.
  - Lorsqu'il y a une détection d'un front montant, le capteur se met en état HIGH.
- Démarrage du chronomètre sur détection
  - Quand un mouvement est capté, pour la première fois:
    - motionDetected = true
    - motionStartTime = millis(), il y a un enregistrement du moment du début du mouvement.
- Vérification de la durée du mouvement
  - Si le mouvement continue est égale ou dépasse 5 secondes alors:
    - La led s'allume.
    - Un message est envoyé sur le terminal:
- Réinitialisation si pas de mouvement
  - motionDeected = false
  - si la led est allumée, et il n'y a plus de mouvement continue: la led s'éteint.

## Patch hepl-SousaJoao-patch-3#
**Objectif :** Réveil du microcôntroleur grâce au capteur PIR BS-612.  

- Configuration des pins du matérielle
  - Le capteur PIR BS-612 est configuré  sur le GPIO13 et la led sur le pin GPIO4.
  - L'initialisation de la led à l'état LOW.
- Réveil par bouton ou capteur
  - Autorisation du réveil depuis l’état de sommeil profond (esp_sleep_enable_ext0_wakeup)
  - Niveau bas sur le bouton ou le capteur déclenche le réveil
  - Permet de garder l’appareil en veille pour économiser de l’énergie
- Gestion du TimerCAM
  - Initialisation du module TimerCAM (TimerCAM.begin(true))
  - Commande d’allumage de la LED via PWM 
  - LED allumée pendant 10 secondes pour indiquer le réveil

- Mise en veille automatique
  - Après affichage / temporisation, l’appareil peut se mettre en veille
  - Le réveil peut être déclenché par :
  - le capteur PIR
  - le bouton physique
  - La fonction TimerCAM.Power.timerSleep(5) déclenche la mise en veille après 5 secondes

- Utilisation du compteur / temporisation
  - vTaskDelay(pdMS_TO_TICKS(10000)) = pause non bloquante pendant 10 secondes avant de lancer la veille
  - Permet d’avoir un délai avant la mise en veille tout en restant compatible avec le multitâche

---
## Patch hepl-SousaJoao-patch-4#  

**Objectif** 
Ce code met en place un système de double réveil pour la TimerCAM :
- Réveil immédiat via le capteur PIR pour signaler un mouvement
- Réveil périodique via le timer RTC toutes les 60 secondes
Le tout en maintenant une consommation minimale grâce au deep sleep et à un timer permanent synchronisé.

1. Configuration matérielle
- LED externe sur le GPIO4
- Capteur PIR sur le GPIO13
- TimerCAM initialisée au démarrage
- RTC interne utilisé pour mesurer le temps et programmer les réveils

2. Gestion des causes de réveil
Au démarrage, le code identifie la source du réveil :

a) Réveil par PIR (EXT0)
- Le PIR est passé à HIGH
- La LED externe s’allume pendant 10 secondes
- Puis elle s’éteint avant le retour en deep sleep
  Ce comportement simule une action simple lors d’un mouvement détecté.

b) Réveil par Timer RTC
- Le timer interne a atteint l’échéance programmée
- Le code affiche simplement : "Reveil par timer permanent"
  Ce réveil sert uniquement à maintenir la synchronisation du timer.

c) Premier démarrage / reset
- Initialisation du timer permanent
- next_wakeup = now + PERIOD_US
  Le premier réveil périodique est programmé exactement 60 secondes plus tard.

3. Timer RTC permanent 
Le code utilise une variable RTC persistante :
RTC_DATA_ATTR uint64_t next_wakeup;

Elle survit au deep sleep et permet de :
- Garder une échéance fixe dans le temps
- Éviter toute dérive, même après plusieurs réveils PIR
- Recalculer la durée restante avant le prochain réveil
Logique :
- On lit l’heure RTC 
- On calcule le temps restant
- Ce temps restant est utilisé pour programmer le prochain réveil timer

Le réveil périodique reste parfaitement aligné toutes les 60 secondes.

4. Réactivation des sources de réveil
Avant chaque deep sleep :
- Le capteur PIR est activé :
esp_sleep_enable_ext0_wakeup(SENSOR_PIN, 1);
- Timer RTC est activé avec la durée restante :
esp_sleep_enable_timer_wakeup;
Ainsi, l’ESP32 peut être réveillé :
- Instantanément par un mouvement
- Régulièrement par le timer interne
- Sans conflit entre les deux mécanismes

5. Deep sleep
Enfin, le module entre en veille profonde:

esp_deep_sleep_start();

Le loop() n’est jamais exécuté : tout se passe dans setup() à chaque réveil.

---

## Patch hepl-SousaJoao-patch-5# 
**Objectif** 

Ce firmware combine deux mécanismes de réveil pour la TimerCAM :
     - Réveil PIR pour allumer une LED lors d’un mouvement
     - Réveil périodique RTC toutes les 60 secondes
Le tout avec une fenêtre PIR de 10 minutes limitant le nombre d’activations à 2, et un timer permanent synchronisé pour éviter toute dérive temporelle.

1. Configuration matérielle
     - LED externe sur le pin GPIO4
     - Capteur PIR sur le pin GPIO13 
     - TimerCAM initialisée au démarrage
     - RTC interne utilisé pour mesurer le temps et gérer les fenêtres

2. Gestion du réveil PIR
Lors d’un réveil par le capteur PIR :
     - Vérification de la fenêtre PIR de 10 minutes :
     - Si première activation ou fenêtre expirée: remise à zéro, déboute une nouvelle fenêtre
     - Limitation à 2 déclenchements de la LED.
     - La LED s'allumée pendant 10 secondes
     - Sinon la LED est ignorée quand la limite est atteinte

Ce mécanisme évite les déclenchements répétés et stabilise la consommation.

3. Réveil par Timer RTC
Si le réveil provient du timer interne :
     - Le code affiche simplement :"Reveil par timer permanent"
Ce réveil n’exécute aucune action fonctionnelle :
il sert uniquement à maintenir la synchronisation du timer permanent.

4. Premier démarrage
 Lors d’un reset ou du tout premier boot :
   - Initialisation du timer permanent :
     - Initialisation de la fenêtre PIR
     - Remise à zéro du compteur PIR

5. Timer RTC permanent 
 Le code utilise une variable RTC persistante :

 Elle permet de :
  - Garder une échéance fixe toutes les 60 secondes
  - Recalculer le temps restant avant le prochain réveil
  - Éviter toute dérive, même après plusieurs réveils PIR
 
 Logique :
  -  Si l’heure actuelle dépasse l’échéance alors on programme la suivante
  -  Sinon, on calcule le temps restant
  -  Ce temps est utilisé pour programmer le réveil RTC

6. Activation des sources de réveil
 Avant chaque deep sleep :
  - Le capteur PIR activé
  - Timer RTC est activé avec la durée restante

Ainsi, l’ESP32 peut être réveillé :

  - Instantanément par le PIR
  - Régulièrement par le timer RTC
  - Sans conflit entre les deux mécanismes

---

## Patch hepl-SousaJoao-patch-6#  
**Objectif** 
Gestion PIR limitée, envoi batterie MQTT et timer RTC synchronisé.
Ce code met en ouvre un fonctionnement basse consommation combinant trois mécanismes indépendants:
- Déclenchement par le capteur PIR limité à deux activations dans une fenêtre de dix minutes.
- Envoi périodique de l’état de la batterie via MQTT lors d’un réveil par timer RTC.
- Deep sleep systématique avec double source de réveil : capteur PIR (EXT0) et timer RTC.
L’ensemble garantit une consommation minimale tout en assurant un comportement prévisible et synchronisé.

1. Configuration matérielle et réseau
- LED sur GPIO4
- PIR sur GPIO13 (réveil EXT0)
- TimerCAM initialisée au démarrage
- Wi‑Fi activé uniquement lors des transmissions MQTT
- MQTT configuré avec un broker local et un topic batterie

2. Gestion du réveil PIR
Lors d’un réveil PIR :
- Vérification de la fenêtre de dix minutes ; réinitialisation si expirée
- Si pir_count < 2, l’activation est acceptée : incrément du compteur et LED allumée dix secondes
- Si la limite est atteinte, aucune action n’est effectuée
Ce mécanisme limite les déclenchements et réduit la consommation.

3. Réveil par timer RTC et envoi de la batterie
Lors d’un réveil TIMER :
- Lecture du niveau et de la tension de batterie
- Construction d’un message unique
- Activation du Wi‑Fi, connexion MQTT, publication sur timercam/battery
- Désactivation immédiate du Wi‑Fi
Le Wi‑Fi n’est utilisé que pour l’envoi, ce qui optimise l’énergie.

4. Premier démarrage
En cas de reset :
- Initialisation du timer permanent, prochaine échéance dans une minute
- Initialisation de la fenêtre PIR
- Remise à zéro du compteur PIR

5. Timer RTC permanent et synchronisation
Le timer utilise next_wakeup stocké en RTC pour maintenir une périodicité stable :
- Si l’échéance est dépassée, une nouvelle est programmée
- Sinon, le temps restant est calculé
- Le timer RTC est configuré avec cette durée
Ce procédé évite toute dérive, même après plusieurs réveils PIR.

6. Activation des sources de réveil
Avant chaque deep sleep :
- Activation du réveil PIR (EXT0)
- Activation du réveil TIMER avec la durée restante
L’ESP32 peut ainsi être réveillé soit par un mouvement, soit par le timer périodique.

---    

## Patch hepl-SousaJoao-patch-7#
**Objectif :** Envoi d'une photo MQTT après détection de mouvement prolongée.  
Le but est de détecter un mouvement via un capteur PIR, attendre que ce mouvement dure au moins 10 secondes, capturer une photo avec la TimerCAM et l’envoyer vers un broker MQTT en morceaux (chunks) encodés en Base64.

- Configuration matérielle
  - Capteur PIR connecté sur la pin 13
  - Lecture en numérique : HIGH = mouvement détecté
  - TimerCAM initialisée en mode caméra JPEG
  - Résolution configurée en XGA 
  - Orientation verticale inversée via set_vflip(1)

- Connexion WiFi
  - Connexion au réseau WiFi défini dans les macros WIFI_SSID et WIFI_PASSWORD
  - Timeout de connexion fixé à 10 secondes 
  - Reconnexion automatique activée
  - Affichage de l’adresse IP en cas de réussite

- Communication MQTT
  - Utilisation de la librairie PubSubClient
  - Connexion au broker MQTT défini par :
    - MQTT_HOST
    - MQTT_PORT
    - MQTT_TOPIC
  - Reconnexion automatique si la communication MQTT est perdue
  - Envoi des messages via mqttClient.publish

- Détection de mouvement
  - La logique du PIR fonctionne en trois phases :
    
    1 - Détection du front montant
       - Passage LOW à HIGH
         
       - Début de la temporisation : motionStart = millis()
         
       - Le flag photoTaken = false réactive la prise de photo

    2 - Maintien du mouvement
       - On attend 10 secondes de mouvement continu
         
       - Condition : millis() - motionStart >= 10000
         
       - Une fois la durée atteinte une photo est capturée

    3 - Fin du mouvement
       - Passage HIGH à LOW
         
       - Reset de l’état du capteur

- Capture et envoi de la photo
  - Prise de vue via TimerCAM en JPEG
  - Découpage de l’image en blocs de 4 KB
  - Encodage en Base64 pour compatibilité MQTT
  - Transmission séquentielle de tous les chunks
  - Libération de la mémoire caméra
    
---

## Patch hepl-SousaJoao-patch-8#
**Objectif :** Envoi d'une photo MQTT après détection de mouvement prolongée avec une mise en veille.  
Détecter un mouvement continu durant 10 secondes, activer le WiFi, envoyer une photo via MQTT, puis repasser l’ESP32 TimerCAM en mode veille profonde avec réveil par le capteur PIR.

- Configuration matérielle
  - Capteur PIR sur GPIO13
  - TimerCAM initialisée en mode JPEG
  - Résolution XGA
  - Orientation verticale ajustée et qualité optimisée
  - Port série actif pour le debug

- Détection de mouvement 
  - Le PIR pilote l’ensemble du fonctionnement à travers trois phases :
    - Début du mouvement
      - Passage de LOW à HIGH.
      - Enregistrement du temps de début.
      - La prise de photo n’est pas encore autorisée.

    - Mouvement continu pendant 10 secondes
      - Si le PIR reste HIGH pendant 10 secondes il y a un déclenchement de la capture.
      - Le système sait que le mouvement est réel et persistant.

    - Fin du mouvement
      - Retour à LOW ainsi le retour à l’état initial.

- Connexion WiFi

  - Activation du WiFi uniquement lorsque la photo doit être envoyée.
  - Connexion au point d’accès défini dans le code.
  - Affichage de l’adresse IP pour vérifier la liaison.
  - Extinction complète du WiFi après envoi pour économiser l’énergie.

- Communication MQTT

  - Configuration du broker: L'adresse IP, port et topic.
  - Connexion MQTT juste avant l’envoi de la photo.
  - Reconnexion si nécessaire.
  - Transmission d’un message texte “Photo taken” après l’image.

- Capture et envoi de la photo

  - Capture JPEG via TimerCAM.
  - Découpage en blocs de 4 KB.
  - Encodage Base64 pour compatibilité MQTT.
  - Envoi séquentiel de chaque chunk identifié par:
    - ID unique: timestamp.
    - Numéro du chunk.
    - Nombre total de chunks.
  - Libération du buffer caméra après transmission.

- Mise en veille après envoi
  
  - Extinction complète du WiFi: disconnect et WIFI_OFF.
  - Attente du retour du PIR à LOW jusqu’à 10 secondes.
  - Configuration du réveil via ext0_wakeup sur le PIR.
  - Passage en deep sleep pendant 20 secondes via TimerCAM si aucune photo est prise.
    - Cela permet :
      - Réduction très forte de la consommation énergétique.
      - Réveil automatique dès qu’un nouveau mouvement est détecté.
---

## Patch hepl-SousaJoaopatch-9#
**Objectif :** Envoi d'une photo MQTT avec flash après détection de mouvement prolongée avec une mise en veille .  
Détecter un mouvement continu durant 10 secondes, signaler la prise de photo via une LED externe, envoyer l’image en plusieurs blocs sur MQTT, puis repasser l’ESP32 TimerCAM en mode veille profonde avec réveil via le PIR.

- Configuration matérielle
  - Capteur PIR connecté sur GPIO13
  - LED externe sur GPIO4
  - TimerCAM initialisée pour capturer en JPEG 
  - Port série configuré pour le suivi en temps réel
  - Paramètres MQTT définis: broker local, topic

- Détection du mouvement
  - Le programme suit l’évolution du signal du PIR :
  - Début du mouvement: LOW à HIGH
  - Enregistrement du temps de début
  - Indication dans le terminal
  - L’appareil se prépare mais ne prend pas encore de photo

- Mouvement continu pendant 10 secondes
  - Vérification via millis()
  - Ce seuil valide que la présence détectée est réelle et prolongée

- Fin du mouvement 
  - Réinitialisation du système
  - Retour en état d’attente

- Indication lumineuse
  - La LED s’allume juste avant la capture photo
  - Elle reste active pendant la transmission MQTT
  - Elle s’éteint 2 secondes après la photo, comme flash

- Connexion WiFi et communication MQTT
  - Activation du WiFi uniquement lors de la prise de photo
  - Connexion au réseau local configuré
  - Connexion MQTT au broker via un client PubSub
  - Envoi d’un message “Photo taken” après le transfert de l’image
  - Désactivation totale du WiFi après transmission

- Capture et envoi de la photo
  - Capture JPEG via TimerCAM
  - Découpage du fichier en blocs de 4 KB
  - Encodage Base64 de chaque bloc
  - Envoi sur le topic MQTT sous forme de paquets :

    - ID de l’image
      - Numéro du bloc
      - Nombre total de blocs
      - Données base64

  - Libération du buffer caméra après transmission

- Mise en veille et gestion du réveil
  - Attente que le PIR repasse à LOW avant d’autoriser la veille
  - Configuration du réveil matériel via ext0_wakeup sur le capteur PIR
  - Passage en mode deep sleep pendant 20 secondes si aucune photo est prise
  - L’ESP32 se réveillera automatiquement lorsqu’un nouveau mouvement est détecté

    - Ce fonctionnement permet :
      - Une détection fiable
      - Une transmission réseau efficace
      - Une consommation d’énergie minimale grâce à la veille profonde

---

## Patch hepl-SousaJoaopatch-10# 
**Objectif :** Détecter un mouvement continu pendant 10 secondes, capturer une photo, l’envoyer en blocs via MQTT, puis remettre la TimerCAM en deep sleep avec double réveil :
   - Par capteur PIR (EXT0) pour prendre les photos
   - Par timer RTC pour l’envoi périodique du niveau de batterie.
 Ce patch combine détection fiable, transmission optimisée, et gestion d’énergie avancée.

1. Configuration matérielle
   - Capteur PIR sur le GPIO13
   - LED externe sur GPIO4
   - TimerCAM initialisée pour capturer en JPEG 
   - WiFi activé uniquement lors des transmissions
   - MQTT : broker local, topics pics et timercam/battery

2. Détection du mouvement avec la PIR:

   - Vérification que le PIR est HIGH 
   - Démarrage d’une fenêtre de 10 secondes via millis()
   - Si le signal reste stable : photo autorisée
   - Sinon : retour immédiat en veille
  Une limite de 2 photos par fenêtre de 10 minutes est imposée via :
   - window_start (timestamp RTC)
   - pir_count => compteur de photos max. 2 photos par fenêtre de temps

3. Capture et envoi de la photo

 Si le mouvement est continu pendant 10 secondes:
   - Initialisation caméra
   - Capture JPEG
   - Découpage en blocs de 4095 bytes
   - Encodage Base64
   - Envoi MQTT sous forme de données_base64
   - Message final : "Photo taken"
   - Libération du buffer caméra
   - Désactivation du WiFi

4. Envoi périodique de la batterie (réveil par le TIMER)
 Toutes les 1 minute, un réveil RTC est déclenché :
   - Lecture tension + pourcentage batterie
   - Connexion WiFi + MQTT
   - Publication sur timercam/battery
   - Retour en deep sleep
 Ce réveil n’interfère pas avec la logique PIR.

5. Gestion des timers RTC 
 a) Réveil toutes les 60 secondes pour envoyer l’état batterie.
    #define PERIOD_US (60ULL * 1000000ULL)

 b) WINDOW_US – Fenêtre PIR de 10 minutes
    Limite de 2 photos par fenêtre de 10 minutes.
    Si la fenêtre expire, pir_count est remis à zéro. 
    #define WINDOW_US (10ULL * 60ULL * 1000000ULL)

 c) next_wakeup – Synchronisation continue
    Stocké en RTC_DATA_ATTR, donc conservé en deep sleep.
    Logique :
   - On calcule le temps restant avant le prochain réveil périodique
   - On programme le timer RTC avec ce temps
   - On met à jour next_wakeup = now + remaining

 Le réveil batterie reste parfaitement synchronisé, même si plusieurs réveils PIR interviennent entre-temps.

  6. Mise en veille et réveils
   
  Avant de dormir :
   - Activation du réveil PIR :
     esp_sleep_enable_ext0_wakeup(SENSOR_PIN, 1)
   - Activation du réveil timer :
     esp_sleep_enable_timer_wakeup(remaining)
   - Passage en deep sleep
 Ce fonctionnement assure :
   - Réactivité avec un réveil instantané sur mouvement
   - Régularité avec le niveau de batterie envoyée toutes les 60 s
   - Économie d’énergie maximale

---

## Patch hepl-SousaJoaopatch-11#
**Objectif** L’objectif est de faire fonctionner la TimerCAM en ultra basse consommation en combinant trois fonctions totalement indépendantes : la prise de photo uniquement lorsqu’un mouvement est validé par le capteur PIR, l’envoi périodique de l’état de la batterie via MQTT, et un mode deep sleep optimisé utilisant deux sources de réveil — le PIR pour les photos et le timer RTC pour les transmissions programmées.

1. Matériel et configuration
   
- Capteur PIR sur le pin GPIO13 (EXT0)
- LED externe sur le pin GPIO4
- Initialisation de la TimerCAM
- Initialisation du Wi-Fi
- Initialisation de la communication par MQTT 

2. Réveil par détection d'un mouvement par le capteur PIR  
 Au réveil par le PIR :

 - Vérification du contexte s'il n'y a pas de blocage ou si la fenêtre PIR active
 - Validation du mouvement :
  - Observation du PIR pendant 10 s
  - Le signal doit rester majoritairement HIGH
  - Sinon: retour en deep sleep
 - Limitation : 2 photos maximum par fenêtre de 12h  
  - window_start = début de fenêtre
  - pir_count = nombre de photos prises

3. Capture & envoi photo
   
Si le mouvement est validé :
- Initialisation caméra
  - Capture d'une image
  - Découpage en blocs de 4095 octets
  - Encodage Base64
  - Envoi MQTT des chunks de la photo
  - Message final : "Photo taken"
  - Libération mémoire + coupure Wi-Fi
- Activation d’un blocage PIR de 5 minutes

4. Blocage PIR
   
Après chaque photo :
- Le PIR est ignoré pendant 5 minutes
- Le timer RTC gère automatiquement la fin du blocage
- Objectif : éviter les rafales et réduire la consommation

5. Batterie réveil par TIMER
   
Un réveil RTC indépendant envoie la batterie toutes les 24 h :
- Lecture tension + le pourcentage de la batterie
- Publication MQTT sur battery
- Coupure Wi-Fi
- Retour en deep sleep
Ce réveil fonctionne même si plusieurs réveils PIR ont eu lieu entre-temps.

6. Gestion des timers RTC
   
- Timer batterie :
- Stocké en RTC
- Toujours aligné sur un multiple exact de 24 h
- Fenêtre PIR :
- Durée : 12 h
- À expiration alors pir_count = 0
- Avant chaque deep sleep :
- Calcul du prochain événement :
- Envoi batterie
- Fin blocage capteur PIR
- Fin fenêtre capteur PIR
- Le plus proche détermine la durée du sommeil

7. Mise en veille
   
Avant de dormir :
- Timer RTC toujours actif
- PIR activé uniquement si : Pas de blocage ou si la fenêtre PIR n'est pas saturée.
- Fenêtre PIR non saturée

Réveil après dormir si :
- Réveil instantané sur mouvement valide
- Batterie envoye les données régulièrement
- Ce qui permet une consommation minimale

---

## Patch hepl-SousaJoaopatch-12#

**Objectif** Faire fonctionner la TimerCAM en ultra basse consommation : capture photo uniquement sur mouvement validé par le PIR, envoi périodique de la batterie via MQTT, et deep sleep optimisé avec GPIO33 pour alimentation de la caméra, capteur PIR et les timers RTC.

1. Matériel et configuration

- Capteur PIR sur le pin GPIO13 (EXT0)
- LED externe sur le pin GPIO4
- Initialisation du  GPIO33 poour commuter la batterie
- Initialisation de la TimerCAM
- Initialisation du Wi-Fi
- Initialisation de la communication par MQTT 
- GPIO 33 est mis sur HIGH en permanence

2. Réveil par détection d'un mouvement par le capteur PIR  
 Au réveil par le PIR :

 - Vérification du contexte s'il n'y a pas de blocage ou si la fenêtre PIR active
 - Validation du mouvement :
  - Observation du PIR pendant 10 s
  - Le signal doit rester majoritairement HIGH
  - Sinon: retour en deep sleep
 - Limitation : 2 photos maximum par fenêtre de 12h  
  - window_start = début de fenêtre
  - pir_count = nombre de photos prises

3. Capture & envoi photo
   
Si le mouvement est validé :
- Initialisation caméra
  - Capture d'une image + envois de la topic de la batterie
  - Découpage en blocs de 4095 octets
  - Encodage Base64
  - Envoi MQTT des chunks de la photo
  - Message final : "Photo taken"
  - Libération mémoire avec coupure Wi-Fi
- Activation d’un blocage PIR de 5 minutes

4. Blocage PIR
   
Après chaque photo :
- Le PIR est ignoré pendant 5 minutes
- Le timer RTC gère automatiquement la fin du blocage
- Objectif : éviter les rafales et réduire la consommation

5. Batterie réveil par TIMER
   
Un réveil RTC indépendant envoie la batterie toutes les 24 h :
- Lecture tension + le pourcentage de la batterie
- Publication MQTT sur battery
- Coupure Wi-Fi
- Retour en deep sleep
Ce réveil fonctionne même si plusieurs réveils PIR ont eu lieu entre-temps.

6. Gestion des timers RTC
   
- Timer batterie :
- Stocké en RTC
- Toujours aligné sur un multiple exact de 24 h
- Fenêtre PIR :
- Durée : 12 h
- À expiration alors pir_count = 0
- Avant chaque deep sleep :
- Calcul du prochain événement :
- Envoi batterie
- Fin blocage capteur PIR
- Fin fenêtre capteur PIR
- Le plus proche détermine la durée du sommeil

7. Mise en veille
   
Avant de dormir :
- Timer RTC toujours actif
- PIR activé uniquement si : Pas de blocage ou si la fenêtre PIR n'est pas saturée.
- Fenêtre PIR non saturée

Réveil après dormir si :
- Réveil instantané sur mouvement valide
- Batterie envoye les données régulièrement
- Ce qui permet une consommation minimale

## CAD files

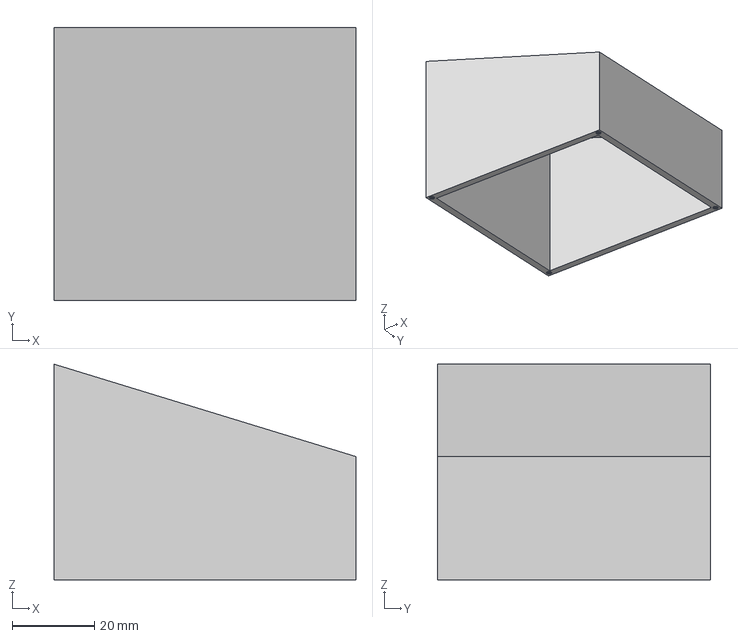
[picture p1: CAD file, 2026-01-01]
Hardware/Modele3d/Volume1/triangle.step
73.5 x 66.4 x 52.5 mm

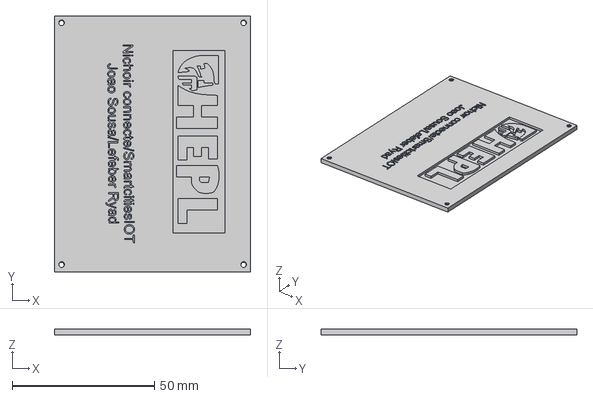
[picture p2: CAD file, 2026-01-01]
Hardware/Modele3d/Volume2/LIDv2.step
69.0 x 90.0 x 2.00 mm

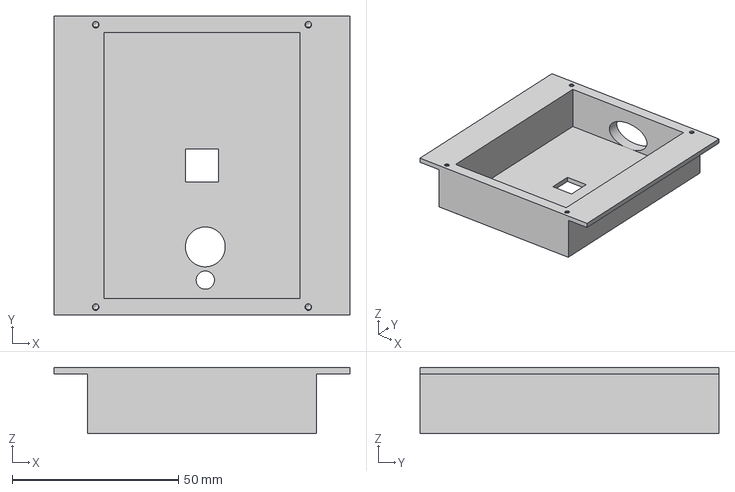
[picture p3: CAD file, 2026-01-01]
Hardware/Modele3d/Volume2/boxv2.step
89.0 x 90.0 x 20.0 mm

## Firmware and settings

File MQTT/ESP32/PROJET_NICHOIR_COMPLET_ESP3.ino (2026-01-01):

#include "M5TimerCAM.h"
#include <WiFi.h>
#include <PubSubClient.h>
#include <esp_sleep.h>
#include "esp32/rtc.h"
#include "base64.h"
#include <WebServer.h>
#include <Preferences.h>
#include "driver/gpio.h"

// ================= GPIO ==================
const int SENSOR_PIN = 13;  // Capteur PIR connecté sur GPIO13
const int LED_PIN    = 4;   // LED utilisée comme indicateur de prise de photo
static const int GPIO33 = 33;
#define CAM_POWER_PIN 32   // GPIO alimentation caméra
// ================= TIMING ==================
// minute pour l'envoi du topic batterie
#define PERIOD_US (24ULL * 60ULL * 60ULL * 1000000ULL)   // Période d'envoi de l'état batterie 24heures
#define WINDOW_US (12ULL * 60ULL * 60ULL * 1000000ULL)   // 12h fenêtre temporelle maximale pendant laquelle 2 photos sont autorisées
#define PIR_BLOCK_US (5ULL * 60ULL * 1000000ULL)         // 5 minutes blocage après photo

// ================= WIFI ==================
Preferences preferences;
WebServer server(80);
// Page HTML de configuration Wi-Fi
String setupPage = R"rawliteral(
<!DOCTYPE html>
<html>
<head><title>ESP32 Wi-Fi Setup</title></head>
<body>
<h2>Change Wi-Fi Credentials</h2>
<form action="/save" method="POST">
  SSID:<br>
  <input type="text" name="ssid"><br><br>
  Password:<br>
  <input type="password" name="password"><br><br>
  <input type="submit" value="Save">
</form>
</body>
</html>
)rawliteral";
// Page principale affichée lorsque l’ESP32 est connecté au Wi-Fi
String mainPageTemplate = R"rawliteral(
<!DOCTYPE html>
<html>
<head><title>ESP32 Wi-Fi Info</title></head>
<body>
<h2>ESP32 is connected to Wi-Fi</h2>
<p>SSID: %SSID%</p>
<p>IP: %IP%</p>
<p><a href="/setup">Change Wi-Fi</a></p>
</body>
</html>
)rawliteral";

// ================= MQTT ==================
#define MQTT_HOST "192.168.178.29"
#define MQTT_PORT 1883
#define MQTT_TOPIC_BATTERY "battery"
#define MQTT_TOPIC_PIC "pics"

// ================= RTC DATA ==================
// Timer batterie INDEPENDANT, en us, basé sur le RTC
// Prochain réveil programmé pour l’envoi batterie (timer RTC indépendant)
RTC_DATA_ATTR uint64_t next_battery_wakeup = 0;

// Début de la fenêtre PIR
RTC_DATA_ATTR uint64_t window_start      = 0;

// Nombre de déclenchements PIR dans la fenêtre courante
RTC_DATA_ATTR uint8_t  pir_count         = 0;

// Horodatage du dernier déclenchement PIR valide
RTC_DATA_ATTR uint64_t last_pir_trigger  = 0;

// Flag non utilisé actuellement 
RTC_DATA_ATTR bool pir_trigger_valid     = false;

// Indique si le PIR est temporairement bloqué après une photo
RTC_DATA_ATTR bool pir_block_active      = false;

// ================= MQTT OBJECTS ==================
WiFiClient espClient;
PubSubClient mqttClient(espClient);

// ==================== WI-FI ====================
bool connectWiFiFromPrefs() {
    preferences.begin("wifi", true);
    String ssid = preferences.getString("ssid", "");
    String password = preferences.getString("password", "");
    preferences.end();

    if (ssid == "") return false;

    WiFi.mode(WIFI_STA);
    WiFi.begin(ssid.c_str(), password.c_str());

    for (int i = 0; i < 20; i++) {
        if (WiFi.status() == WL_CONNECTED) return true;
        delay(500);
    }
    return false;
}

void handleMain() {
    String page = mainPageTemplate;
    page.replace("%SSID%", WiFi.SSID());
    page.replace("%IP%", WiFi.localIP().toString());
    server.send(200, "text/html", page);
}

void handleSetup() {
    server.send(200, "text/html", setupPage);
}

void handleSave() {
    String ssid = server.arg("ssid");
    String password = server.arg("password");

    preferences.begin("wifi", false);
    preferences.putString("ssid", ssid);
    preferences.putString("password", password);
    preferences.end();

    server.send(200, "text/html", "<p>Saved! ESP32 will restart...</p>");
    delay(2000);
    ESP.restart();
}

// ==================== MQTT ====================
void connectMQTT() {
    mqttClient.setServer(MQTT_HOST, MQTT_PORT);
    while (!mqttClient.connected()) {
        mqttClient.connect("TimerCAM_Client");
        delay(500);
    }
}

// ==================== PHOTO ====================
void sendPhotoInChunks() {
    if (!TimerCAM.Camera.get()) return;
    uint8_t* buf = TimerCAM.Camera.fb->buf;
    size_t len   = TimerCAM.Camera.fb->len;
    size_t chunkSize = 4095;
    int totalChunks = (len + chunkSize - 1) / chunkSize;
    String imageID = String(millis());

    for (int i = 0; i < totalChunks; i++) {
        size_t start = i * chunkSize;
        size_t sz = min(chunkSize, len - start);
        String base64Chunk = base64::encode(buf + start, sz);
        String payload = imageID + "|" + String(i) + "|" + String(totalChunks) + "|" + base64Chunk;
        mqttClient.publish(MQTT_TOPIC_PIC, payload.c_str());
        mqttClient.loop();
        delay(20);
    }
    TimerCAM.Camera.free();
}

void sendPhotoTakenNotification() {
    mqttClient.publish(MQTT_TOPIC_PIC, "Photo taken");
    digitalWrite(LED_PIN, LOW);
    Serial.println("Photo send");
    digitalWrite(CAM_POWER_PIN, LOW);
    unsigned long t0 = millis();
    while (millis() - t0 < 500) {
        mqttClient.loop();
        delay(10);
    }
}

// ======== NOUVELLE FONCTION POUR ENVOI BATTERIE ========
void sendBattery() {
    int batteryVoltage = TimerCAM.Power.getBatteryVoltage();
    int batteryLevel   = TimerCAM.Power.getBatteryLevel();
    char batteryMsg[40];
    sprintf(batteryMsg, "%d,%d", batteryLevel, batteryVoltage);

    if (connectWiFiFromPrefs()) {
        connectMQTT();
        mqttClient.publish(MQTT_TOPIC_BATTERY, batteryMsg);
        unsigned long t0 = millis();
        while (millis() - t0 < 700) { mqttClient.loop(); delay(20); }
        delay(300);
        WiFi.disconnect(true);
    }

    // Réinitialisation du timer batterie 24h après envoi avec photo
    next_battery_wakeup = esp_rtc_get_time_us() + PERIOD_US;
}

// ==================== SLEEP ====================
void goToSleep() {
    uint64_t now = esp_rtc_get_time_us();
   
    // Couper BT
    btStop();
    // Couper caméra
    digitalWrite(CAM_POWER_PIN, LOW);
    // 1) Initialisation du timer batterie si nécessaire
    if (next_battery_wakeup == 0) {
        // Alignement sur un multiple entier de PERIOD_US
        next_battery_wakeup = now - (now % PERIOD_US) + PERIOD_US;
    }

    // 2) Temps jusqu'au prochain envoi batterie (INDEPENDANT de la PIR)
    uint64_t t_bat;
    if (next_battery_wakeup > now) {
        t_bat = next_battery_wakeup - now;
    } else {
        t_bat = 0; // on est déjà en retard, on réveillera tout de suite pour envoyer
    }

    // 3) Temps jusqu'aux événements liés à la PIR (blocage / fin de fenêtre)
    uint64_t t_pir_timer = UINT64_MAX;

    if (pir_block_active) {
        uint64_t block_end = last_pir_trigger + PIR_BLOCK_US;
        if (block_end > now) {
            t_pir_timer = block_end - now;
        } else {
            t_pir_timer = 0;  // blocage déjà terminé
        }
    } else if (pir_count >= 2 && window_start != 0) {
        uint64_t window_end = window_start + WINDOW_US;
        if (window_end > now) {
            t_pir_timer = window_end - now;
        } else {
            t_pir_timer = 0;  // fenêtre déjà terminée
        }
    }

    // 4) On dort jusqu'au prochain événement : min(batterie, PIR)
    uint64_t sleep_time = t_bat;
    if (t_pir_timer < sleep_time) sleep_time = t_pir_timer;
    if (sleep_time == 0) sleep_time = 1000000ULL; // sécurité: au moins 1s

    // Timer toujours activé sert pour batterie + PIR timers
    esp_sleep_enable_timer_wakeup(sleep_time);

    // EXT0 (PIR) activé uniquement si pas de blocage et pas de fenêtre saturée
    bool pir_window_saturee = (pir_count >= 2 && window_start != 0);
    if (!pir_block_active && !pir_window_saturee) {
        esp_sleep_enable_ext0_wakeup((gpio_num_t)SENSOR_PIN, 1);
    }
       WiFi.disconnect(true);
    gpio_hold_en(GPIO_NUM_33);
    gpio_deep_sleep_hold_en();
    delay(200);
    esp_deep_sleep_start();

}

// ==================== SETUP ====================
void setup() {

    pinMode(CAM_POWER_PIN, OUTPUT);
    digitalWrite(CAM_POWER_PIN, LOW);
    // ===== POWER HOLD (CRITIQUE) =====
    gpio_set_direction(GPIO_NUM_33, GPIO_MODE_OUTPUT);
    gpio_set_level(GPIO_NUM_33, 1);      // maintien alim
    gpio_hold_en(GPIO_NUM_33);           // fige l'état
    gpio_deep_sleep_hold_en();           // conserve en deep sleep
    // =================================
    
    Serial.begin(115200);
    delay(500);

    pinMode(SENSOR_PIN, INPUT_PULLUP);
    pinMode(LED_PIN, OUTPUT);
    digitalWrite(LED_PIN, LOW);
    TimerCAM.begin(true);
  

    uint64_t now = esp_rtc_get_time_us();
    esp_sleep_wakeup_cause_t reason = esp_sleep_get_wakeup_cause();

// ================= Wi-Fi SETUP MODE =================
    if (!connectWiFiFromPrefs()) {
    Serial.println("[WiFi] No saved credentials, starting AP mode");
    WiFi.mode(WIFI_AP);
    WiFi.softAP("ESP32-Setup", "12345678");
    Serial.print("[AP] Connect to: "); Serial.println("ESP32-Setup");
    Serial.print("[AP] Open browser to: "); Serial.println(WiFi.softAPIP());

    server.on("/", handleMain);
    server.on("/setup", handleSetup);
    server.on("/save", HTTP_POST, handleSave);
    server.begin();

    while (true) {
        server.handleClient();
        delay(10);
    }
}
    // ================= PIR WAKEUP =================
    if (reason == ESP_SLEEP_WAKEUP_EXT0) {
        Serial.println("Reveil par PIR");

        if (pir_block_active) goToSleep();

        if (window_start == 0 || (now - window_start) > WINDOW_US) {
            window_start = now;
            pir_count = 0;
        }

        if (pir_count < 2) {
            unsigned long windowStart = millis();
            int samples = 0, highCount = 0;
            while (millis() - windowStart < 10000) {
                samples++;
                if (digitalRead(SENSOR_PIN) == HIGH) highCount++;
                delay(50);
            }

            // Rejet si signal instable
            if ((float)highCount / samples < 0.7) goToSleep();

            pir_count++;
            //  Allumer caméra
            digitalWrite(CAM_POWER_PIN, HIGH);

            if (!TimerCAM.Camera.begin()) goToSleep();
             
             // Configuration caméra
            TimerCAM.Camera.sensor->set_pixformat(TimerCAM.Camera.sensor, PIXFORMAT_JPEG);
            TimerCAM.Camera.sensor->set_framesize(TimerCAM.Camera.sensor, FRAMESIZE_XGA);
            TimerCAM.Camera.sensor->set_vflip(TimerCAM.Camera.sensor, 1);
            TimerCAM.Camera.sensor->set_quality(TimerCAM.Camera.sensor, 3);

            digitalWrite(LED_PIN, HIGH);

            if (connectWiFiFromPrefs()) {
                connectMQTT();
                sendPhotoInChunks();
                sendPhotoTakenNotification();
                sendBattery();  // ENVOI BATTERIE SIMULTANÉ AVEC PHOTO ET RESET TIMER 24H
            }

            last_pir_trigger = now;
            pir_block_active = true;

            WiFi.disconnect(true);
            delay(300);
            
            Serial.println("Sleep");
            goToSleep();
        }

        goToSleep();
    }

    // ================= TIMER WAKEUP =================
    else if (reason == ESP_SLEEP_WAKEUP_TIMER) {
        Serial.println("Reveil par TIMER");

        // 1) Gestion des états PIR basés sur le temps (blocage, fenêtre)
        if (pir_block_active && now - last_pir_trigger >= PIR_BLOCK_US) {
            pir_block_active = false;
        }

        if (window_start != 0 && (now - window_start) >= WINDOW_US) {
            window_start = now;
            pir_count = 0;
        }

        // 2) Gestion du timer batterie INDEPENDANT
        if (next_battery_wakeup == 0) {
            next_battery_wakeup = now - (now % PERIOD_US) + PERIOD_US;
        }

        bool doit_envoyer_batterie = (now >= next_battery_wakeup);

        if (doit_envoyer_batterie) {
            int batteryVoltage = TimerCAM.Power.getBatteryVoltage();
            int batteryLevel   = TimerCAM.Power.getBatteryLevel();
            char batteryMsg[40];
            sprintf(batteryMsg, "%d,%d", batteryLevel, batteryVoltage);

            if (connectWiFiFromPrefs()) {
                connectMQTT();
                mqttClient.publish(MQTT_TOPIC_BATTERY, batteryMsg);
                unsigned long t0 = millis();
                while (millis() - t0 < 700) { mqttClient.loop(); delay(20); }
                delay(300);
                WiFi.disconnect(true);
            }

             // Avance sans dérive du timer batterie
            while (next_battery_wakeup <= now) {
                next_battery_wakeup += PERIOD_US;
            }
        }

        goToSleep();
    }

    // ================= FIRST BOOT =================
    else {
        // Initialisation propre au tout premier démarrage
        window_start      = now;
        pir_count         = 0;
        pir_block_active  = false;
        pir_trigger_valid = false;

        next_battery_wakeup = now - (now % PERIOD_US) + PERIOD_US;

        goToSleep();
    }
}

void loop() {
    // Si AP mode actif, gérer le serveur
    if (WiFi.getMode() == WIFI_AP) {
        server.handleClient();
    }
}

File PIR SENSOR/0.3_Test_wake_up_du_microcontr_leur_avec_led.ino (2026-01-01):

#include "M5TimerCAM.h"
#include <esp_sleep.h>

const int LED_PIN = 4;        // LED externe GPIO4
const int SENSOR_PIN = 13;    // PIR sur GPIO13

void setup() {

    pinMode(SENSOR_PIN, INPUT_PULLUP);

    // Réveil par capteur (niveau bas = 0 → HIGH = 1 selon ton PIR)
    esp_sleep_enable_ext0_wakeup((gpio_num_t)SENSOR_PIN, 1);

    // Initialisation du TimerCAM
    TimerCAM.begin(true);

    pinMode(LED_PIN, OUTPUT);

    Serial.begin(115200);
    Serial.println("Wake up!!!");

    // LED ON pendant 10 secondes
    analogWrite(LED_PIN, 255);
    delay(10000);

    // Reconfigurer le réveil par capteur AVANT sleep
    esp_sleep_enable_ext0_wakeup((gpio_num_t)SENSOR_PIN, 1);

    Serial.println("sleep!!");

    // Dormir 5 secondes (deep sleep TimerCAM)
    TimerCAM.Power.timerSleep(5);
}

void loop() {
}

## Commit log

2025-11-27 First test to save MQTT data send by ESP32 into a database
2025-11-27 Premier Test avec MQTT et une database
    Le code enregistre les messages envoyés par l’ESP32 via le protocole MQTT et les stocke dans une base de données.
2025-11-27 Premières images envoyées de l’ESP32 vers le Raspberry Pi et stockage dans la base de données.
    Le code enregistre dans la base de données les images envoyées en un seul paquet via MQTT.
2025-11-27 Code pour assembler une photo envoyée en plusieurs morceaux afin de la traiter
    Le script permet de recevoir une photo divisée en plusieurs morceaux, ce qui permet d’augmenter la résolution de la caméra en envoyant plus de données. Le code assemble ensuite les différents morceau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
2025-12-20 Enhance Flask app with battery data
    Refactor Flask app to include battery info and improve comments.
2025-12-20 fichier index pour la première application d'un web serbveur
2025-12-20 changement du fichier index seulement pour les pics
2025-12-20 flask avec topic de la batterie et les images
2025-12-20 changement de l'index pour les topics de la batterie et les pics
    Updated HTML structure and added comments for clarity.
2025-12-20 Revise README to document recent application updates
    Updated the README to reflect recent patches and features added to the Flask web server application, including HTML pages for displaying MQTT messages and images, as well as battery management.
2026-01-01 MQTT_DATABASE_PICS+BATTERY
    Updated MQTT and database configuration, added image handling, and improved error handling.
2026-01-01 Mise à jour du README pour gestion des images et batterie
    Ajout de la gestion des images en plusieurs morceaux et de la réception des informations de batterie via MQTT. Mise à jour des callbacks pour gérer simultanément les topics d'images et de batterie.
2026-01-01 Add MQTT to MariaDB integration script
    This script connects to a MariaDB database and a MQTT broker, creating a table for storing messages and inserting received messages into the database.
